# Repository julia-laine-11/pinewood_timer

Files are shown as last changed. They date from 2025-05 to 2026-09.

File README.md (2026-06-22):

# pinewood_timer
Timer system for a pinewood derby track. My grandma asked me to help her make one since her boy scout troop's track does not have one. I hope that I can make these more affordable so that her troop and other troops can get accurate timers that dont cost an arm and a leg.

*so whats in here?*
### [Hardware:](https://github.com/julia-laine-11/pinewood_timer/tree/main/Hardware)
* display_15_in
    - schematic
    - pcb
    - holds all the 7-segment displays and sensor receivers at the end of the track

* mainboard
    - schematic
    - pcb
    - holds the brains for the system
    - also where the power cable goes

### [Software:](https://github.com/julia-laine-11/pinewood_timer/blob/main/Software/code.md)
  - readme
* [Program](https://github.com/julia-laine-11/pinewood_timer/tree/main/Software/code/pinewood_program)
  - platformio project

### Overview
#### Overall Requirements
- easy operation -> plug and play
- 4 lanes
- time to the thousandths
- displays time in each lane
- displays placement in each lane
- cost less than $100-$120
    - 

##### Requirements per each lane
- start sensor - same trigger for all lanes
- stop sensor - seperate per each lane
- time display - 4 seven seg displays
- placement display - 1 larger seven seg display

##### Sensors
- Start sensor triggered by lever release
  - Microswitch is easy to install and get output from
  - I have to wait and see what my grandfather builds as the start mechanism
- Stop sensor - IR LED and IR Receiver
  - Sits in the middle of the groove the cars ride on underneath the finish line
  - Since it will likely be in a gym, the IR receiver should point down for less interference from the large lamps
  - A comparator or the STM ADC can be used if the voltage doesnt drop to an amount the STM recognizes as 0

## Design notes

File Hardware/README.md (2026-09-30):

## Contents:

so i am editing this board right now. i took the senior design pcb and made it into a zombie version that might connect to this.

some fixes that will be made:

- d+ - flip
- connector footprint
- stm connection

- [display_15_in](https://github.com/julia-laine-11/pinewood_timer/tree/main/Hardware/display_15_in)
*will be printed
   - whats inside:
    - kicad project
      - schematic
      - pcb
  - about:
    - combines placement_disp and timer_display_pcb since it is cheaper to put both on the same pcb - even though its so much larger
    - also includes the sensors for the end of track

- [mainboard](https://github.com/julia-laine-11/pinewood_timer/tree/main/Hardware/mainboard)
*will be printed
  - whats inside:
    - kicad project
      - schematic
      - pcb
  - about:
    - main board where the stm32f091rct6 lives
    - jst connectors to each board/input/output around the system

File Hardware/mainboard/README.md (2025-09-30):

## mainboard

This board will be placed in a central location on the track. It connects to the power, reset button, start sensors, display at the end, and end sensors. A usb-c power supply will power it.

#### Current Board

9/30/25 - today i soldered the LED on. i got scared it wasnt working, but it turns out it was just a blue LED and therefore needed a smaller resistor. Then i plugged it in and i thought hte JTAG was backwards, but it turns out the decoup capacitors I placed are not in face decoupling and just capacitors. so i removed them and added a wire around them. im having issues connecting to the board. 

i got access to the board files from ece362, so i plan on comparing my layout to theirs to see what i did wrong. im disappointed but i think i can fix it (hopefully)



#### Current schematic
8/7/25 - fixed little silkscreen words. fixed DRC violations



### Old:

8/5/25 - i actually routed stuff today wohoo. i also added the design rules because i forgot to do that












not too much changed about the schematic:

i just added this for the start switch because i forgot about it


8/3/25 - added connectors and sheets









7/27/25 - organized and fixed power



7/26/25 - changed stm. added jtag. added usb for power. edited 3v3 supply. current schematic messy but its still in the works



Unfinished schematic

missing:
- connectors
- power in
- jtag
- usb - ttl



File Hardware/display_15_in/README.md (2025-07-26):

## display_15_in
This was originally going to be a few seperate boards. I thought it would be easier and cheaper to make. 

It turns out to be cheaper to do it this way since the price of printing 3-4 boards per track and the price of 1 big one is the same. Also, with multiple boards you have to buy connectors and this 1 large board needs way less than 4 small ones.

This board connects to the main board with 1 8x2 connector and 1 12x2 connector.

### Parts
- LTS-3401LG - single 7-seg displays
- 4x TDCR1050M - quad 7-seg displays
- 20x PN2907A - cathode select bjt
- 20x 150 Ohm - mux to bjt
- 16x 47 Ohm - driver to display
- 2x 74HC138 - mux
- 2x TLC59211 - driver

#### pictures



>size comparison of digits 

#### schematics








#### PCB

Updated:

- still needs
  - power and ground traces
  - drill holes for mounting
  - test points

All traces routed (for now)











#### Log

7/12/25 - moved all of the components needed over to one project

7/13/25 - worked out connections between sheets and found connectors for mainboard. began layout (no traces)

7/19/25 - laying more traces and revising old ones. i am starting to hate the connector but i must use it



7/20/25 - sorted out the connector from hell. well, i at least made it better. i also discovered the "distribute evenly" and "align" functions



7/25/25 - finished traces, added test points



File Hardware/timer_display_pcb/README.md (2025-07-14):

## timer_display_pcb
This PCB will not be used. the [display_15_in](https://github.com/julia-laine-11/pinewood_timer/tree/main/Hardware/display_15_in) will be used instead

### Parts
4x TDCR1050M - 7-seg displays
16x PN2907A - cathode select bjt
16x 150 Ohm - mux to bjt
16x 47 Ohm - driver to display
2x 74HC138 - mux
2x TLC59211 - driver

### Pictures

Circuit:





Timer display vs placement display sizing



[comment]: <>
[comment]: <>
[comment]: <>
[comment]: <>

#### PCB V1
I am writing this as V1 since I am coming to the realization that it is the same price to order three seperate boards and connecting them together as it is to just buy one 3"x15" PCB. I will probably still order one of these since 5x is $2.00, but for the actual track it will be easier to install just one board.

- Schematic



[comment]: <>

- Front




[comment]: <>
[comment]: <>
- Back




[comment]: <>
[comment]: <>

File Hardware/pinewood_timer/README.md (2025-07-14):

## pinewood_timer

This is just a schematic of the overall system. it has gotten messy as I have gutted it to use its pieces in other parts of the project.

This will not be printed or used but I plan to clean it up when I am done

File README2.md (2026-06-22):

# Pinewood Derby Timer — Software & Operations Guide

A four-lane pinewood derby finish-line timer built around the **STM32F091RCT6**.  
This document describes the firmware, pin map, serial interface, and day-of-race behavior.

> The original project readme is unchanged at [README.md](README.md).  
> Firmware file index: [Software/code/pinewood_program/INDEX.md](Software/code/pinewood_program/INDEX.md)

---

## What it does

- **Four independent lane timers** start together when the release lever triggers **PC11**.
- Each timer **stops** when its car breaks the IR beam at the finish (**PB11–PB14**).
- **Quad 7-segment displays** above each lane show elapsed time to **0.001 s** (e.g. `1.234`).
- **Large placement digits** show finish order (1st, 2nd, …) as each car crosses; other lanes keep counting until they finish.
- **Reset** clears times and placements (GPIO button on **PA15**, or serial `R`).
- **Status LEDs** on the mainboard: READY / RUNNING / FINISHED.
- **Serial output** over **USART5** (**PC12** TX, **PD2** RX) at 115200 baud via an **FT232RL** USB-TTL adapter.

---

## Hardware context

| Board | Role |
|---|---|
| **mainboard** | STM32, power, JTAG, connectors, status LEDs, start/reset |
| **display_15_in** | All 7-segment displays, IR receivers, TLC59211 drivers, 74HC138 mux |

Display driving: **TLC59211** LED drivers (parallel D1–D8 + CLK) and **74HC138** decoders for digit/lane multiplexing. See KiCad schematics under `Hardware/`.

---

## Toolchain

- **MCU:** STM32F091RCT6 @ 48 MHz
- **IDE:** VS Code + PlatformIO
- **Upload:** JTAG / SWD via OpenOCD (`Software/code/pinewood_program/openocd.cfg`)
- **Serial:** FT232RL on USART5 — **PC12** (MCU TX) and **PD2** (MCU RX)

### Build

```bash
cd Software/code/pinewood_program
pio run
pio run -t upload
pio device monitor -b 115200
```

Wire FT232RL: **MCU PC12 → adapter RX**, **MCU PD2 ← adapter TX**, common GND.

---

## Pin map (MCU)

Every mask is the bit index in the GPIO port (bit *N* = pin **PN**).

### Timer displays

| Pins | Port | Lanes |
|---|---|---|
| PB0–PB7 | GPIOB | Segment data (TLC59211 D1–D8), lanes 1–2 |
| PB8–PB10 | GPIOB | Mux A0–A2 (74HC138) |
| PC0–PC7 | GPIOC | Segment data, lanes 3–4 |
| PC8–PC10 | GPIOC | Mux A0–A2 |

### Placement displays

| Pins | Port | Role |
|---|---|---|
| PA0–PA7 | GPIOA | Segment data |
| PA8–PA10 | GPIOA | Mux A0–A2 |

### Sensors & buttons

| Pin | Hex mask | Input |
|-----|---|---|
| **PC11** | `0x0800` | Start — shared by all lanes |
| **PA15** | `0x8000` | Reset button *(placeholder; change in `pins.h` if routed elsewhere)* |
| **PB11** | `0x0800` | Lane 1 finish IR |
| **PB12** | `0x1000` | Lane 2 finish IR |
| **PB13** | `0x2000` | Lane 3 finish IR |
| **PB14** | `0x4000` | Lane 4 finish IR |

**Note:** **PC12** is **not** the reset button — it is **USART5_TX**.

### Serial (USART5 / “UART5”)

| Pin | Hex mask | Direction |
|-----|---|---|
| **PC12** | `0x1000` | TX → FT232RL RX |
| **PD2** | `0x0004` | RX ← FT232RL TX |

### Status LEDs (active high)

| Pin | Hex mask | Meaning |
|-----|---|---|
| **PC13** | `0x2000` | READY (idle) |
| **PC14** | `0x4000` | RUNNING |
| **PC15** | `0x8000` | FINISHED |

Full definitions with comments: [`Software/code/pinewood_program/src/pins.h`](Software/code/pinewood_program/src/pins.h).

---

## Operation

1. Power on — **READY** LED on, serial prints `PINEWOOD READY`.
2. Press reset (or send `R`) if needed to clear a previous race.
3. Release the start lever — all four timers begin; **RUNNING** LED on; serial prints `START`.
4. As each car crosses the finish IR, that lane’s time **freezes**, placement digit appears, serial prints e.g. `FIN 1 2847 1` (lane 1, 2.847 s, 1st place).
5. When all four have finished, **FINISHED** LED on.
6. Reset for the next heat.

Lanes that have not finished continue to increment on the display; finished lanes show their frozen time and placement.

---

## Serial protocol

Baud: **115200**, 8 data bits, no parity, 1 stop bit.

### Automatic messages (MCU → PC)

```
PINEWOOD READY
START
FIN <lane> <time_ms> <place>
RESET
```

- `<lane>` — 1 to 4  
- `<time_ms>` — integer milliseconds (display as `<time_ms>/1000` seconds)  
- `<place>` — 1 to 4  

Example: `FIN 2 3102 2` → lane 2 finished second with time 3.102 s.

### Commands (PC → MCU)

| Character | Action |
|---|---|
| `R` or `r` | Reset race |
| `?` | Reply with state and all lane times |

Example query response: `STATE 1 T1 1200 T2 980 T3 0 T4 0`  
(`STATE` 0=idle, 1=running, 2=finished; `T1`…`T4` in ms)

---

## Firmware architecture

```
main.c          Boot, GPIO, timers, ISRs
clock.c         48 MHz clock
pins.h          Pin map and mux constants
race.c          State machine, 1 kHz time base, placement queue
display.c       2 kHz display multiplexing
uart.c          USART5 logging and commands
font.h          7-segment patterns
```

### Timing (matches [Software/code.md](Software/code.md))

| Rate | Source | Task |
|---|---|---|
| 1 kHz | TIM14 | Increment each running lane timer |
| 2 kHz | TIM6 | Debounce inputs; refresh timer L1–2, L3–4, placement displays |

### Time format

Internal value is an integer counting **milliseconds** at 1 kHz.  
The display always shows a decimal point after the first digit: value `1234` → **1.234**.

### Placement algorithm

Queue starts at **1234** (meaning places 1, 2, 3, 4 are still to assign):

1. Next place = `queue / 1000`
2. Update queue = `(queue % 1000) * 10`

First finisher gets **1**, second **2**, and so on.

---

## Configuration

Edit [`Software/code/pinewood_program/src/pins.h`](Software/code/pinewood_program/src/pins.h):

| Macro | Purpose |
|---|---|
| `RESET_PORT` / `RESET_PIN_MASK` | Reset button location (default **PA15**) |
| `BUTTON_ACTIVE_HIGH` | Set to 0 if switches pull low when pressed |
| `FINISH_SENSOR_ACTIVE_HIGH` | Set to 0 if IR pulls low when beam breaks |
| `lane*_mux_addr` presets | Tune if wrong digit or lane lights up |

---

## Troubleshooting

| Symptom | Check |
|---|---|
| No upload | JTAG wiring, `openocd.cfg`, power to board |
| Garbled serial | 115200 baud, TX/RX not swapped, common GND |
| Timer never starts | **PC11** start wiring and `BUTTON_ACTIVE_HIGH` |
| Lane never stops | Finish pin **PB11–PB14** and `FINISH_SENSOR_ACTIVE_HIGH` |
| Wrong display digit | Mux constants in `pins.h` (380/580/680/700 presets) |
| Reset does nothing | **PA15** routing, or use serial `R` |

---

## Repository layout

```
pinewood_timer/
├── README.md              ← original readme (do not replace)
├── README2.md             ← this file
├── Hardware/              ← KiCad PCBs and schematics
└── Software/
    ├── code.md            ← original firmware design notes
    └── code/pinewood_program/
        ├── INDEX.md       ← source file index
        ├── platformio.ini
        ├── openocd.cfg
        └── src/           ← firmware
```

---

Built for scout troops who need an accurate, affordable track timer. Good luck at the derby.

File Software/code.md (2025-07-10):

I am using an stm32f091rct6 for this project
- vscode with platformio extension
- jtag and usb to ttl

vars

- 1x placement -> int 1234
  
    when ir sensor crossed 
    1234 / 1000 (as an int) gives 1st number
    to update: (1234 % 1000) * 10 brings it to 2340 and its ready for the next one

- 4x times -> int xxxx
  
    dp is always on so i dont have to deal with decimals :)
    counts up to 1 with each 1khz tick
        starts -> interrupt enabled by lever
        stops  -> interrupt disabled by lever

- 4x running -> 1 or 0
      0 at reset
      1 when lever
      0 when ir crossed

control 

faster than 1khz (probs 2k is ok)
- check lever
- check ir lane 1 
- check ir lane 2
- check ir lane 3
- check ir lane 4

faster than updates (1k < refresh rate < 2k)
- run lanes 1 & 2 disp
- run lanes 2 & 3 disp
- run score disp

exactly 1khz
- update time for each lane

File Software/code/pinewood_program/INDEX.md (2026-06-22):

# Pinewood Timer — Software Index

Documentation map for the PlatformIO firmware in this folder.  
For project background and hardware overview, see [README2.md](../../README2.md) at the repo root.

---

## Quick links

| Document | Purpose |
|---|---|
| [README2.md](../../README2.md) | Full project readme (software + operation) |
| [../code.md](../code.md) | Original design notes (variables, timing plan) |
| [../../README.md](../../README.md) | Original repo readme (unchanged) |
| [platformio.ini](platformio.ini) | Build, upload, and monitor settings |
| [openocd.cfg](openocd.cfg) | JTAG / SWD upload via OpenOCD |
| [src/pins.h](src/pins.h) | **Authoritative GPIO pin map** |

---

## Source files

| File | Role |
|---|---|
| [src/main.c](src/main.c) | Entry point, GPIO setup, timer init, ISR wiring |
| [src/clock.c](src/clock.c) | 48 MHz PLL from internal HSI |
| [src/pins.h](src/pins.h) | Pin names, masks, mux presets, polarity flags |
| [src/race.c](src/race.c) | Race state machine, timers, placement queue, sensor debounce |
| [src/race.h](src/race.h) | Public race API and `race_state_t` enum |
| [src/display.c](src/display.c) | 7-segment multiplexing (TLC59211 + 74HC138) |
| [src/display.h](src/display.h) | Display driver API |
| [src/font.h](src/font.h) | Segment patterns for digits 0–9 |
| [src/uart.c](src/uart.c) | USART5 serial (PC12 TX, PD2 RX), `printf` retarget |
| [src/uart.h](src/uart.h) | UART init and race log helpers |

---

## Interrupts and timing

| IRQ handler | Timer | Rate | Work |
|---|---|---|---|
| `TIM14_IRQHandler` | TIM14 | **1 kHz** | Increment running lane times |
| `TIM6_DAC_IRQHandler` | TIM6 | **2 kHz** | Poll start/reset/finish inputs; mux displays; update status LEDs |
| `USART3_4_5_6_IRQHandler` | USART5 | async | Handle serial commands (`R`, `?`) |

System clock: **48 MHz** (`board_build.f_cpu` in `platformio.ini`).

---

## GPIO summary

### Displays (output)

| Bank | MCU pins | Function |
|---|---|---|
| Placement | **PA0–PA10** | 4 large placement digits |
| Timer L1–L2 | **PB0–PB10** | Quad 7-seg timers, lanes 1 & 2 |
| Timer L3–L4 | **PC0–PC10** | Quad 7-seg timers, lanes 3 & 4 |

Each bank: **PA/PB/PC 0–7** = segment data, **8–10** = 74HC138 mux A0–A2.

### Inputs

| Pin | Mask | Function |
|-----|---|---|
| **PC11** | `0x0800` | Start lever (all lanes) |
| **PA15** | `0x8000` | Reset button (placeholder pin) |
| **PB11** | `0x0800` | Lane 1 finish IR |
| **PB12** | `0x1000` | Lane 2 finish IR |
| **PB13** | `0x2000` | Lane 3 finish IR |
| **PB14** | `0x4000` | Lane 4 finish IR |

### UART5 (FT232RL)

| Pin | Mask | Function |
|-----|---|---|
| **PC12** | `0x1000` | USART5_TX → adapter RX |
| **PD2** | `0x0004` | USART5_RX ← adapter TX |

### Status LEDs (output, active high)

| Pin | Mask | LED |
|-----|---|-----|
| **PC13** | `0x2000` | READY |
| **PC14** | `0x4000` | RUNNING |
| **PC15** | `0x8000` | FINISHED |

---

## Serial protocol (115200 8N1)

**MCU → PC (automatic on events)**

| Line | Meaning |
|---|---|
| `PINEWOOD READY` | Boot complete |
| `START` | Race started |
| `FIN <lane> <time> <place>` | Lane finished (lane 1–4, time in ms, place 1–4) |
| `RESET` | Race cleared |

**PC → MCU (send single character)**

| Key | Action |
|-----|---|
| `R` or `r` | Reset race |
| `?` | Print state and four lane times |

---

## Race logic (from `code.md`)

- **Time** — 16-bit counter per lane; +1 every 1 ms while running. Display as **d.ddd** (e.g. `1234` → **1.234** s).
- **Placement queue** — starts at `1234`; each finish takes `queue/1000` as place, then `queue = (queue % 1000) * 10`.
- **Running flag** — per lane; cleared when that lane’s IR triggers.
- **States** — `IDLE` → `RUNNING` → `FINISHED` (or back to `IDLE` on reset).

---

## Build and upload

```bash
cd Software/code/pinewood_program
pio run
pio run -t upload
pio device monitor
```

Upload uses OpenOCD + JTAG (`openocd.cfg`). Serial monitor: **115200** baud.

---

## Tuning checklist

1. **Wrong digit / lane on display** — edit mux presets in [src/pins.h](src/pins.h) (`0x017C`, `0x0244`, `0x02A8`, `0x02BC`).
2. **Sensor polarity wrong** — set `BUTTON_ACTIVE_HIGH` / `FINISH_SENSOR_ACTIVE_HIGH` in [src/pins.h](src/pins.h).
3. **Reset pin moved** — update `RESET_PORT` / `RESET_PIN_MASK` in [src/pins.h](src/pins.h) (PC12 is UART TX).
4. **No serial** — check FT232 wiring to PC12/PD2 and COM port in PlatformIO monitor.

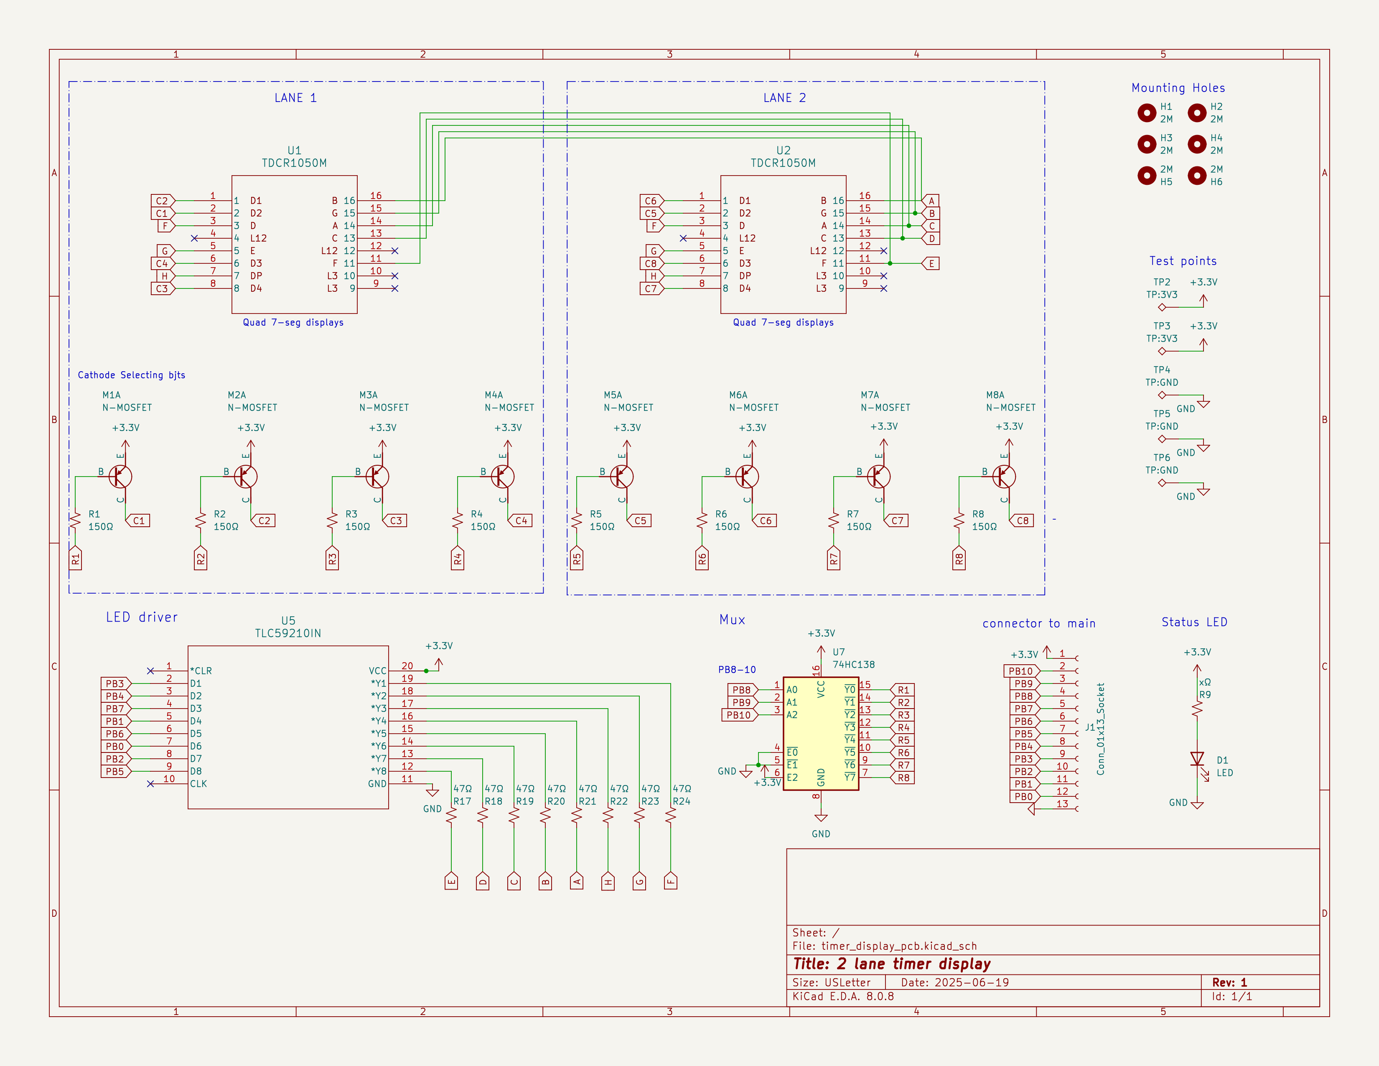
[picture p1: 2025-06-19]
Hardware/timer_display_pcb/schematic.png

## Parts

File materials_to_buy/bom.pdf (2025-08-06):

part # | Description | # | $ single $ all
1 | PT204-6B | IR SENSOR | 25 0.23600 | $5.90
2 | MMBT4403 | TRANSISTOR - DISPLAY SELECT | 125 0.04420 | $5.53
3 | SN74HC138DR | MUX | 25 0.16200 | $4.05
4 | RK73B2ATTD151J | 150 OHM | 125 0.01390 | $1.74
5 | TLC59211IPWR | LED DRIVER | 12 1.09600 | $13.15
6 | RK73B2ATTD510J | 51 OHM | 140 0.01390 | $1.95
7 | IR333-A | IR LED | 25 0.29600 | $7.40
8 | 302-S101 | JTAG CONNECTOR | 10 0.22400 | $2.24
9 | KUSBX-SMT-CS-6-BTR | USB-C PORT | 10 0.61900 | $6.19
10 | SMAZ5V1-13-F | DIODE | 15 0.16600 | $2.49
11 | CL21A226KQQNNNE | 22UF CAPACITOR | 20 0.11500 | $2.30
12 | C0805C103K5RACTU | 10,000PF CAPACITOR | 10 0.02000 | $0.20
13 | CL21B105KBFNNNE | 1UF CAPACITOR | 20 0.01900 | $0.38
14 | CC0805KRX7R9BB104 | .1UF CAPACITOR | 50 0.01600 | $0.80
15 | CC0805JRNPO9BN100 | 10PF CAPACITOR | 20 0.04800 | $0.96
16 | ECS-2520MV-160-CN-TR | 16MHZ CAP | 10 0.96600 | $9.66
17 | 60900213421 | BOOT JUMPER | 10 0.27900 | $2.79
18 | CRGCQ0805F220R | 220 OHM | 30 0.02720 | $0.82
19 | RR1220P-103-D | 10K OHM | 10 0.03100 | $0.31
20 | RC0805FR-071K5L | 1K5 OHM | 10 0.01600 | $0.16
21 | CL21A106KOQNNNE | 10UF | 10 0.05100 | $0.51
22 | LTL-4234 | GREEN LED | 35 0.10200 | $3.57
23 | AMS1117-3.3 | LINEAR REG | 10 0.18200 | $1.82
24 | STM32F091RCT6 | MICROCONTROLLER | 6 6.08000 | $36.48
25 | ILHB0805ER121V | FERRITE BEAD | 10 0.07400 | $0.74
26 | S16B-PHDSS | 16 PIN HEADER | 10 0.43400 | $4.34
27 | PTS636SK25FSMTR LFS | RESET BUTTON | 10 0.21100 | $2.11
28 | PHDR-16VS | 16 PIN HEADER - CONNECTOR | 10 0.23300 | $2.33
29 | 0513532400 | 24 PIN HEADER | 10 0.66800 | $6.68
30 | 0559592430 | 24 PIN HEADER - CONNECTOR | 10 0.92600 | $9.26

total: $136.86
5x: | $27.37
3x: | $45.62

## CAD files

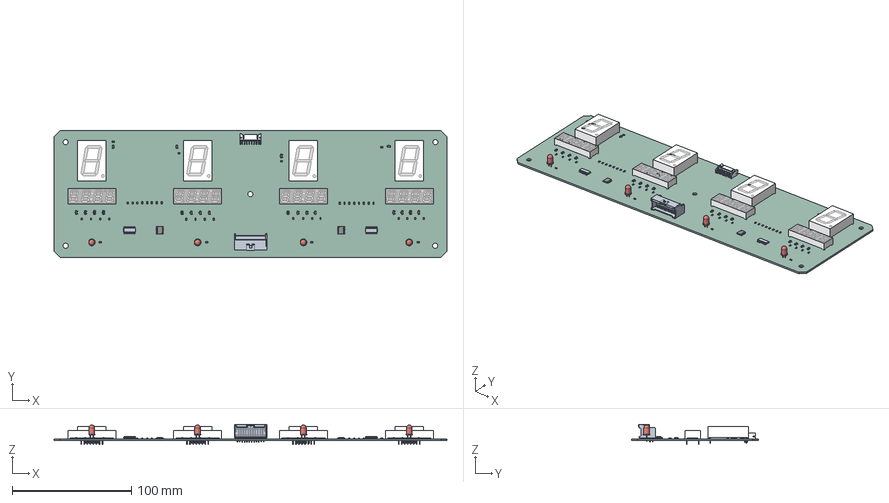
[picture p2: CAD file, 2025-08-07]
Hardware/display_15_in/display_15_in.step
330.2 x 106.7 x 17.1 mm
R_0805_2012Metric x 40
F415-6 x 4
LED_D5.0mm x 4
XDxx25x x 4
D16 x 2
S16B-PHDSS
PW20 x 2
display_15_in_PCB

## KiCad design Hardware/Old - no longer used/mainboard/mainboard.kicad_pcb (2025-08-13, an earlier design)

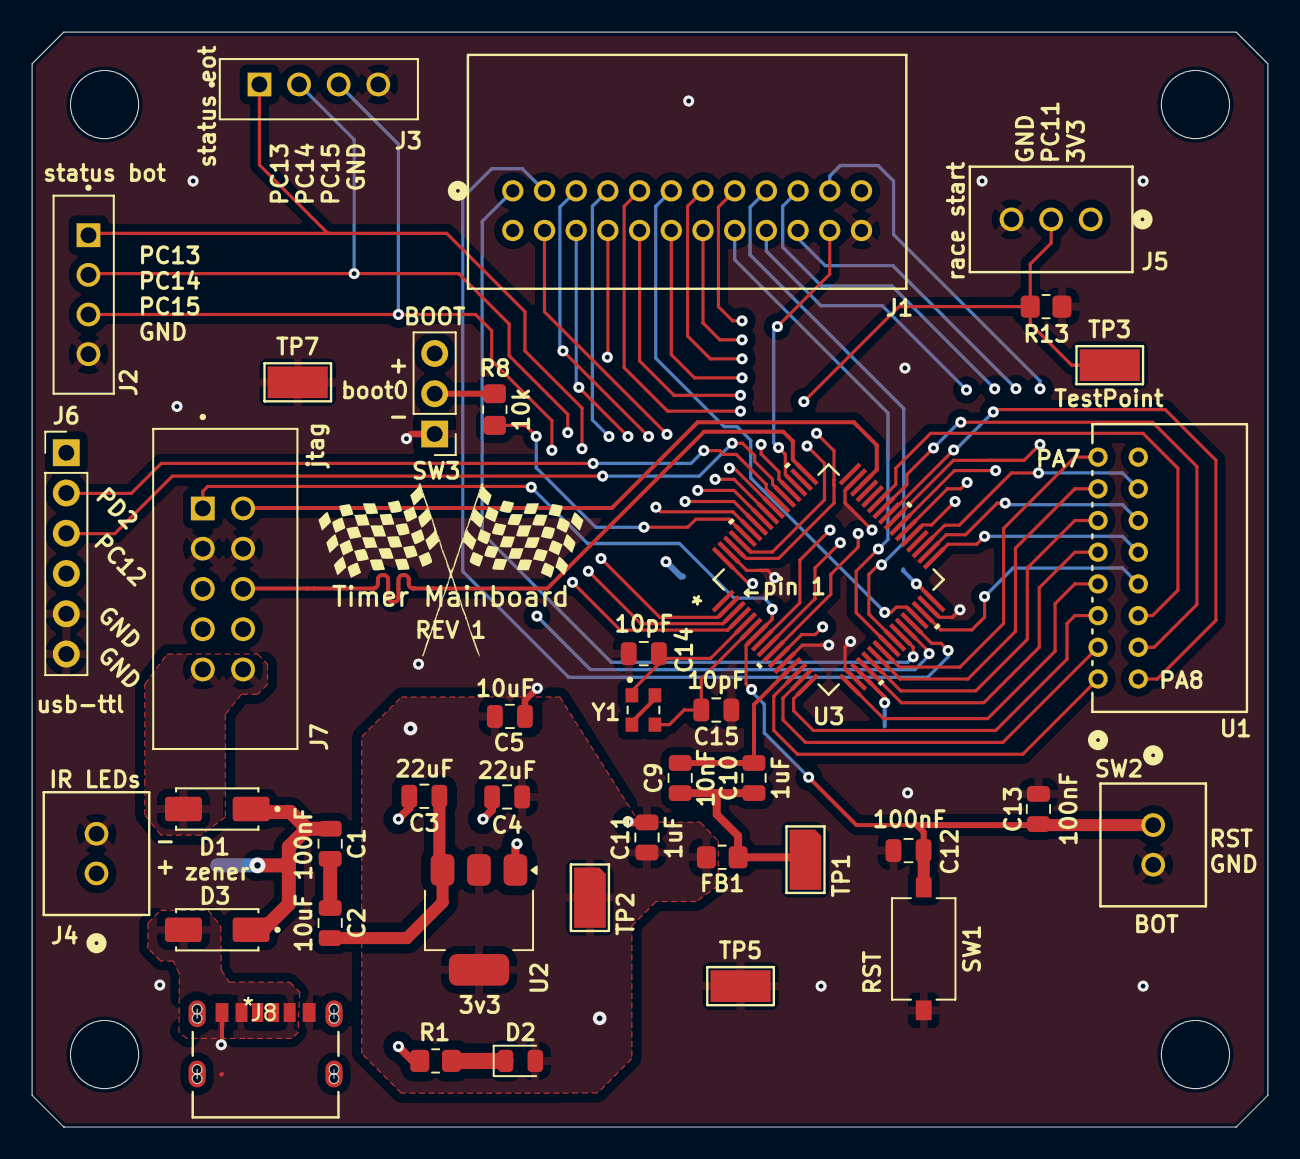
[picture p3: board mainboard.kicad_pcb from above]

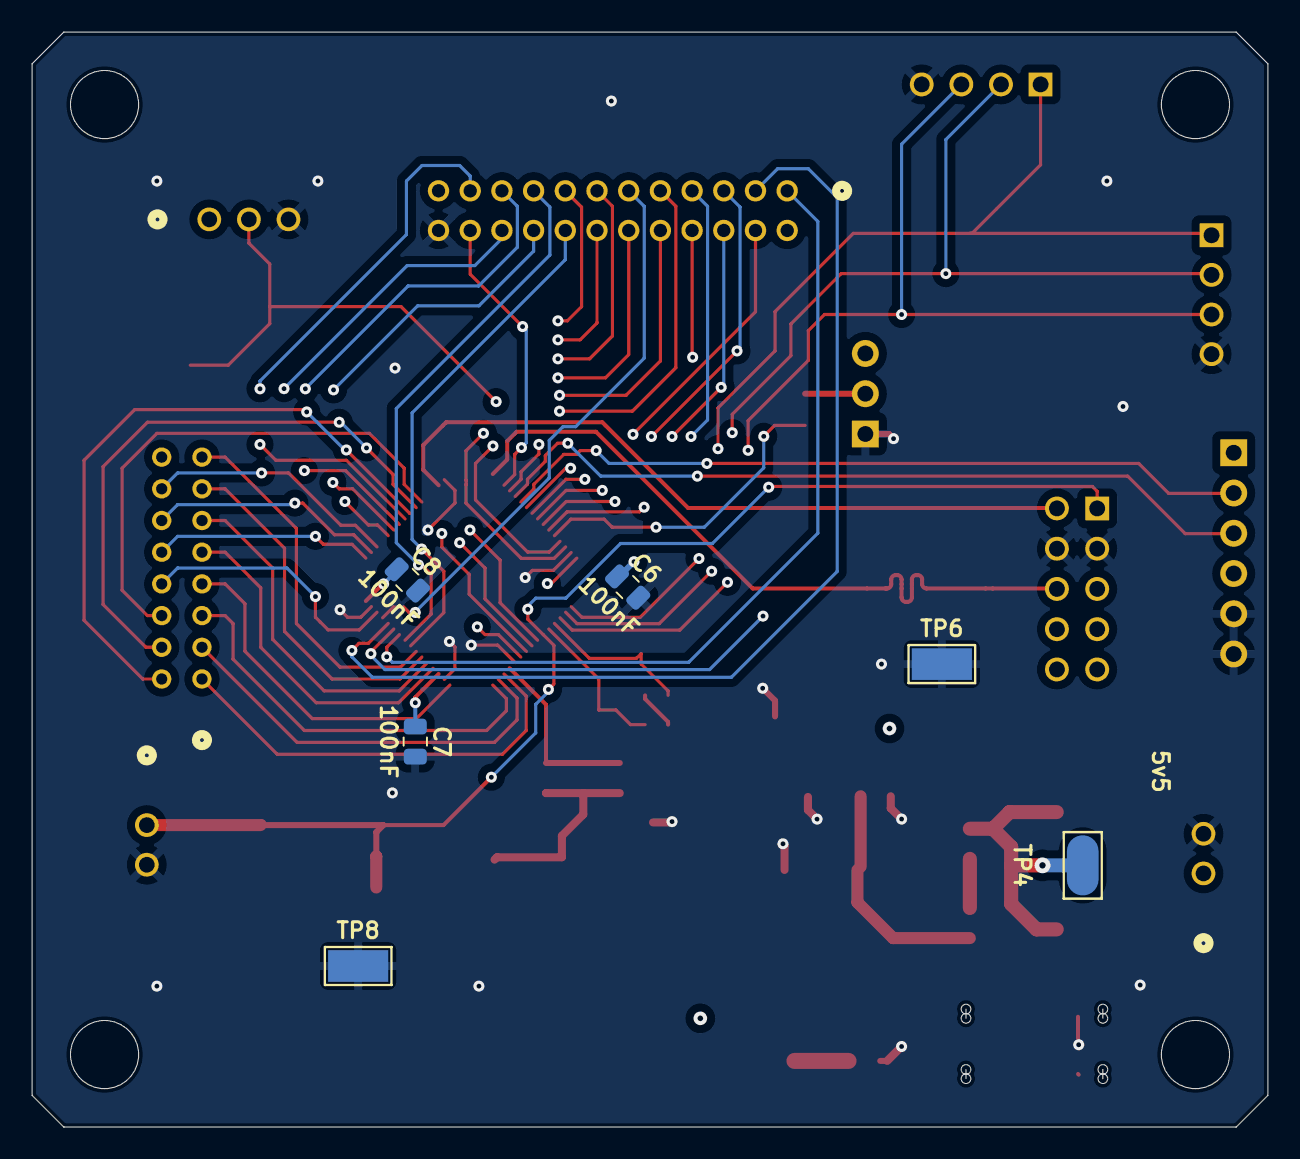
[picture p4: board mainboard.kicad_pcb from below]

Board: 4 copper layers, 78.0 x 69.1 mm, 49 parts (6 on the bottom side), 61 nets.

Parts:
C1, C6, C7, C8, C12, C13: 100nF; C_0805_2012Metric
C2, C5: 10uF; C_0805_2012Metric
C3, C4: 22uF; C_0805_2012Metric
C9: 10nF; C_0805_2012Metric
C10, C11: 1uF; C_0805_2012Metric
C14, C15: 10pF; C_0805_2012Metric
D1, D3: zener; DIOM5226X240N
D2: LED; D_0805_2012Metric
FB1: FerriteBead; R_0805_2012Metric_Pad1.20x1.40mm_HandSolder
H1, H2, H3, H4: MountingHole; MountingHole_4.3mm_M4_DIN965
J1: 559592430; CONN24_559592430_MOL
J2: status bot; 1x04_jst
J3: status eot; 1x04_jst
J4: B02B-XASK-1LFSN; 1X02_JST
J5: race start; 1X03_JST
J6: usb-ttl; PinHeader_1x06_P2.54mm_Vertical
J7: jtag; SULLINS_SBH11-PBPC-D05-ST-BK
J8: KUSBX-SMT-CS-6-BTR; 2171750001_MOL
R1: 1k5; R_0805_2012Metric_Pad1.20x1.40mm_HandSolder
R8: 10k; R_0805_2012Metric_Pad1.20x1.40mm_HandSolder
R13: R_US; R_0805_2012Metric_Pad1.20x1.40mm_HandSolder
SW1: ON-BOARD; SW_Tactile_SPST_NO_Straight_CK_PTS636Sx25SMTRLFS
SW2: BOT; CONN_B02B-XASK-1LFSN_JST
SW3: BOOT; PinHeader_1x03_P2.54mm_Vertical
TP1, TP2, TP3, TP4, TP5, TP6, TP7, TP8: TestPoint; TestPoint_Keystone_5019_Minature
U1: S16B-PHDSSLFSN; S16B-PHDSSLFSN_JST
U2: AMS1117-3.3; SOT-223-3_TabPin2
U3: STM32F091RCTx; STM32F091RCT6-M
Y1: Crystal_GND24; OSC_ECS-2520S25-250-FN-TR

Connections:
+3.3V: C4.1, C5.1, C6.1, C7.1, C8.1, C11.1, D2.2 (A), FB1.2, J1.23, J4.1, J5.1, SW3.3 (C), TP2.1, U2.2 (VO), U3.19 (VDD), U3.32 (VDD), U3.64 (VDD)
+3.3VA: C9.1, C10.1, FB1.1, TP1.1
/programming/3V3 REG DECOUP: C1.2, C2.1
/programming/3v3_reg_in: C2.2, C3.1, U2.3 (VI)
/programming/5v5_in_jtag: D1.2, J7.9, J7.10
/programming/5v5_post_diode: C1.1, D1.1, D3.1, TP4.1
/programming/5v5_usb: D3.2, J8.A9 (VBUS), J8.B9 (VBUS)
/programming/PWR_LED_CATHODE: D2.1 (K), R1.2
/stm/BOOT0: R8.2, U3.60 (PF11)
/stm/HSE_IN: C14.1, U3.5 (PF0), Y1.1
/stm/HSE_OUT: C15.1, U3.6 (PF1), Y1.3
/stm/SW_BOOT0: R8.1, SW3.2 (B)
GND: C3.2, C4.2, C5.2, C6.2, C7.2, C8.2, C11.2, C12.2, C13.2, C14.2, C15.2, J1.24, J2.4, J3.4, J4.2, J5.3, J6.5, J6.6, J7.3, J7.4, J8.A12 (GND), J8.B12 (GND), R1.1, R13.2, SW1.2 (B), SW2.2 (B), SW3.1 (A), TP5.1, TP6.1, TP7.1, TP8.1, U2.1 (GND), U3.12 (VSSA), U3.18 (VSS), U3.31 (VSS), U3.47 (VSS), U3.63 (VSS)
unnamed: C9.2, C10.2, U3.13 (VDDA)
unnamed: Y1.2, Y1.4
PA0: U1.1, U3.14 (PA0)
PA1: U1.2, U3.15 (PA1)
PA2: U1.3, U3.16 (PA2)
PA3: U1.4, U3.17 (PA3)
PA4: U1.5, U3.20 (PA4)
PA5: U1.6, U3.21 (PA5)
PA6: U1.7, U3.22 (PA6)
PA7: U1.8, U3.23 (PA7)
PA8: U1.9, U3.41 (PA8)
PA9: U1.10, U3.42 (PA9)
PA10: U1.11, U3.43 (PA10)
PB0: J1.1, U3.26 (PB0)
PB1: J1.2, U3.27 (PB1)
PB2: J1.3, U3.28 (PB2)
PB3: J1.4, U3.55 (PB3)
PB4: J1.5, U3.56 (PB4)
PB5: J1.6, U3.57 (PB5)
PB6: J1.7, U3.58 (PB6)
PB7: J1.8, U3.59 (PB7)
PB8: J1.9, U3.61 (PB8)
PB9: J1.10, U3.62 (PB9)
PB10: J1.11, U3.29 (PB10)
PB11: U1.12, U3.30 (PB11)
PB12: U1.13, U3.33 (PB12)
PB13: U1.14, U3.34 (PB13)
PB14: U1.15, U3.35 (PB14)
PC0: J1.12, U3.8 (PC0)
PC1: J1.13, U3.9 (PC1)
PC2: J1.14, U3.10 (PC2)
PC3: J1.15, U3.11 (PC3)
PC4: J1.16, U3.24 (PC4)
PC5: J1.17, U3.25 (PC5)
PC6: J1.18, U3.37 (PC6)
PC7: J1.19, U3.38 (PC7)
PC8: J1.20, U3.39 (PC8)
PC9: J1.21, U3.40 (PC9)
PC10: J1.22, U3.51 (PC10)
PC11: J5.2, R13.1, TP3.1, U3.52 (PC11)
PC12: J6.3, U3.53 (PC12)
PC13: J2.1, J3.1, U3.2 (PC13)
PC14: J2.2, J3.2, U3.3 (PC14)
PC15: J2.3, J3.3, U3.4 (PC15)
PD2: J6.2, U3.54 (PD2)
RST: C12.1, C13.1, J7.1, SW1.1 (A), SW2.1 (A), U3.7 (NRST)
SWCLK: J7.6, U3.49 (PA14)
SWDIO: J7.2, U3.46 (PA13)

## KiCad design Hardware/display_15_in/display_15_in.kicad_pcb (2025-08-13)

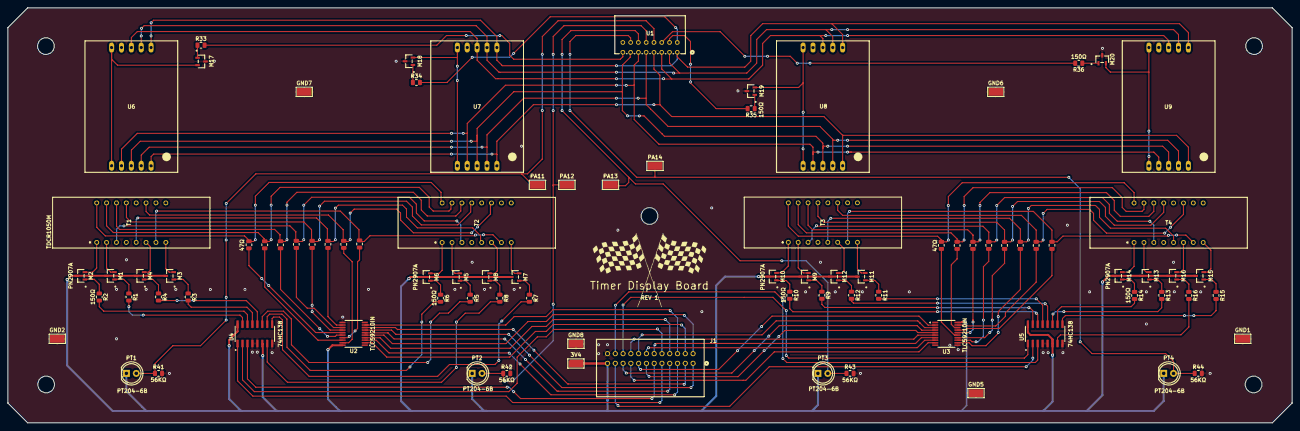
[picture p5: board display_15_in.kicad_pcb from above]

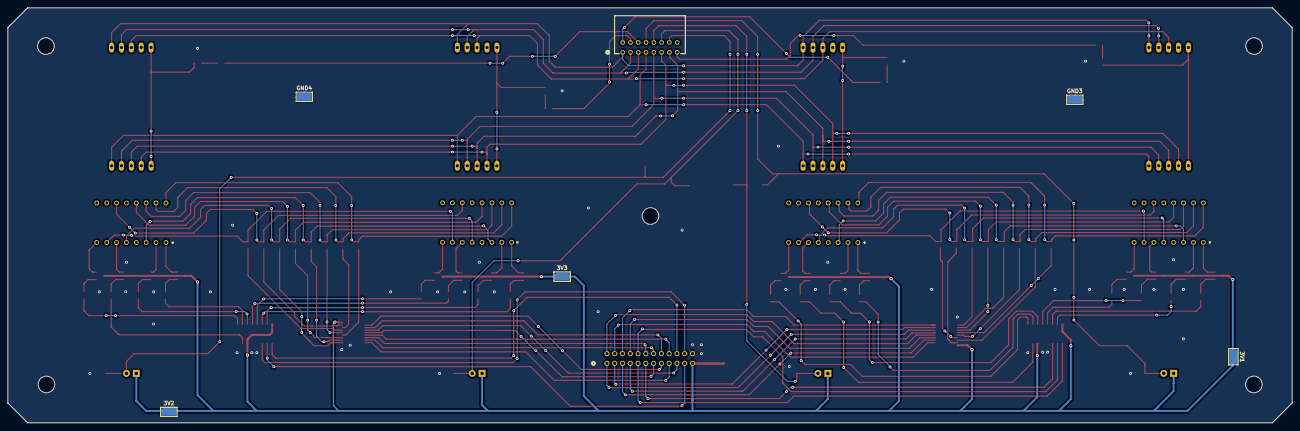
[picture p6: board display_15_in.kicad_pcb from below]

Board: 2 copper layers, 330.2 x 106.7 mm, 94 parts (5 on the bottom side), 127 nets.

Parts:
3V1, 3V2, 3V3, 3V4: TestPoint; TestPoint_Keystone_5019_Minature
GND1, GND2, GND3, GND4, GND5, GND6, GND7, GND8: TestPoint; TestPoint_Keystone_5019_Minature
J1: 559592430; CONN24_559592430_MOL
M1, M3, M4, M5, M6, M7, M8, M9, M10, M11, M12, M13, M14, M15, M16, M17, M18, M19, M20: N-MOSFET; TO-236AB_SOT23_NEX
M2: PN2907A; TO-236AB_SOT23_NEX
PA11, PA12, PA13, PA14: TP; TestPoint_Keystone_5019_Minature
PT1, PT2, PT3, PT4: LED_D5.0mm
R1, R2, R3, R4, R5, R6, R7, R8, R9, R10, R11, R12, R13, R14, R15, R16, R33, R34, R35, R36: 150Ω; R_0805_2012Metric
R17, R18, R19, R20, R21, R22, R23, R24, R25, R26, R27, R28, R29, R30, R31, R32: 47Ω; R_0805_2012Metric
R41, R42, R43, R44: 56KΩ; R_0805_2012Metric
T1, T2, T3, T4: TDCR1050M; TDCG1060M_VIS
U1: S16B-PHDSSLFSN; S16B-PHDSSLFSN_JST
U2, U3: TLC59210IN; SOP65P640X120-20N
U4, U5: 74HC138; SOIC127P600X175-16N
U6, U7, U8, U9: SA39-12YWA; LDS-AA14RI

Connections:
+3.3V: 3V1.1, 3V2.1, 3V3.1, 3V4.1, J1.23, M1.3, M2.3, M3.3, M4.3, M5.3, M6.3, M7.3, M8.3, M9.3, M10.3, M11.3, M12.3, M13.3, M14.3, M15.3, M16.3, PT1.1 (+), PT2.1 (+), PT3.1 (+), PT4.1 (+), U2.20 (VCC), U3.20 (VCC), U4.6 (E2), U4.16 (VCC), U5.6 (E2), U5.16 (VCC)
/plc_disp/CA1: M17.2, U6.1 (CA), U6.6 (CA)
/plc_disp/CA2: M18.2, U7.1 (CA), U7.6 (CA)
/plc_disp/CA3: M19.2, U8.1 (CA), U8.6 (CA)
/plc_disp/CA4: M20.2, U9.1 (CA), U9.6 (CA)
/plc_disp/P_SEL_1: M17.1, R33.1
/plc_disp/P_SEL_2: M18.1, R34.1
/plc_disp/P_SEL_3: M19.1, R35.1
/plc_disp/P_SEL_4: M20.1, R36.1
/tim_disp/A: R21.2, T1.14, T2.14
/tim_disp/A2: R29.2, T3.14, T4.14
/tim_disp/B: R20.2, T1.16, T2.16
/tim_disp/B2: R28.2, T3.16, T4.16
/tim_disp/C: R19.2, T1.13, T2.13
/tim_disp/C1: M1.2, T1.2
/tim_disp/C2: M2.2, T1.1
/tim_disp/C3: M3.2, T1.8
/tim_disp/C4: M4.2, T1.6
/tim_disp/C5: M5.2, T2.2
/tim_disp/C6: M6.2, T2.1
/tim_disp/C7: M7.2, T2.8
/tim_disp/C8: M8.2, T2.6
/tim_disp/C9: M9.2, T3.2
/tim_disp/C10: M10.2, T3.1
/tim_disp/C11: M11.2, T3.8
/tim_disp/C12: M12.2, T3.6
/tim_disp/C13: M13.2, T4.2
/tim_disp/C14: M14.2, T4.1
/tim_disp/C15: M15.2, T4.8
/tim_disp/C16: M16.2, T4.6
/tim_disp/C_2: R27.2, T3.13, T4.13
/tim_disp/D: R18.2, T1.3, T2.3
/tim_disp/D2: R26.2, T3.3, T4.3
/tim_disp/DP1: R22.2, T1.7, T2.7
/tim_disp/DP2: R30.2, T3.7, T4.7
/tim_disp/E: R17.2, T1.5, T2.5
/tim_disp/E2: R25.2, T3.5, T4.5
/tim_disp/F: R24.2, T1.11, T2.11
/tim_disp/F2: R32.2, T3.11, T4.11
/tim_disp/G: R23.2, T1.15, T2.15
/tim_disp/G2: R31.2, T3.15, T4.15
/tim_disp/R1: R1.2, U4.15 (~Y0)
/tim_disp/R2: R2.2, U4.14 (~Y1)
/tim_disp/R3: R3.2, U4.13 (~Y2)
/tim_disp/R4: R4.2, U4.12 (~Y3)
/tim_disp/R5: R5.2, U4.11 (~Y4)
/tim_disp/R6: R6.2, U4.10 (~Y5)
/tim_disp/R7: R7.2, U4.9 (~Y6)
/tim_disp/R8: R8.2, U4.7 (~Y7)
/tim_disp/R25: R9.2, U5.15 (~Y0)
/tim_disp/R26: R10.2, U5.14 (~Y1)
/tim_disp/R27: R11.2, U5.13 (~Y2)
/tim_disp/R28: R12.2, U5.12 (~Y3)
/tim_disp/R29: R13.2, U5.11 (~Y4)
/tim_disp/R30: R14.2, U5.10 (~Y5)
/tim_disp/R31: R15.2, U5.9 (~Y6)
/tim_disp/R32: R16.2, U5.7 (~Y7)
GND: GND1.1, GND2.1, GND3.1, GND4.1, GND5.1, GND6.1, GND7.1, GND8.1, J1.24, M17.3, M18.3, M19.3, M20.3, R41.2, R42.2, R43.2, R44.2, U2.11 (GND), U3.11 (GND), U4.4 (~E0), U4.5 (~E1), U4.8 (GND), U5.4 (~E0), U5.5 (~E1), U5.8 (GND)
unnamed: M1.1, R1.1
unnamed: M2.1, R2.1
unnamed: M3.1, R3.1
unnamed: M4.1, R4.1
unnamed: M5.1, R5.1
unnamed: M6.1, R6.1
unnamed: M7.1, R7.1
unnamed: M8.1, R8.1
unnamed: M9.1, R9.1
unnamed: M10.1, R10.1
unnamed: M11.1, R11.1
unnamed: M12.1, R12.1
unnamed: M13.1, R13.1
unnamed: M14.1, R14.1
unnamed: M15.1, R15.1
unnamed: M16.1, R16.1
unnamed: R24.1, U2.19 (*Y1)
unnamed: R23.1, U2.18 (*Y2)
unnamed: R22.1, U2.17 (*Y3)
unnamed: R21.1, U2.16 (*Y4)
unnamed: R20.1, U2.15 (*Y5)
unnamed: R19.1, U2.14 (*Y6)
unnamed: R18.1, U2.13 (*Y7)
unnamed: R17.1, U2.12 (*Y8)
unnamed: R32.1, U3.19 (*Y1)
unnamed: R31.1, U3.18 (*Y2)
unnamed: R30.1, U3.17 (*Y3)
unnamed: R29.1, U3.16 (*Y4)
unnamed: R28.1, U3.15 (*Y5)
unnamed: R27.1, U3.14 (*Y6)
unnamed: R26.1, U3.13 (*Y7)
unnamed: R25.1, U3.12 (*Y8)
PA0: U1.1, U6.10 (A), U7.10 (A), U8.10 (A), U9.10 (A)
PA1: U1.2, U6.9 (B), U7.9 (B), U8.9 (B), U9.9 (B)
PA2: U1.3, U6.8 (C), U7.8 (C), U8.8 (C), U9.8 (C)
PA3: U1.4, U6.5 (D), U7.5 (D), U8.5 (D), U9.5 (D)
PA4: U1.5, U6.4 (E), U7.4 (E), U8.4 (E), U9.4 (E)
PA5: U1.6, U6.2 (F), U7.2 (F), U8.2 (F), U9.2 (F)
PA6: U1.7, U6.3 (G), U7.3 (G), U8.3 (G), U9.3 (G)
PA7: R33.2, U1.8
PA8: R34.2, U1.9
PA9: R35.2, U1.10
PA10: R36.2, U1.11
PA11: PA11.1, PT1.2 (-), R41.1, U1.12
PA12: PA12.1, PT2.2 (-), R42.1, U1.13
PA13: PA13.1, PT3.2 (-), R43.1, U1.14
PA14: PA14.1, PT4.2 (-), R44.1, U1.15
PB0: J1.1, U2.7 (D6)
PB1: J1.2, U2.5 (D4)
PB2: J1.3, U2.8 (D7)
PB3: J1.4, U2.2 (D1)
PB4: J1.5, U2.3 (D2)
PB5: J1.6, U2.9 (D8)
PB6: J1.7, U2.6 (D5)
PB7: J1.8, U2.4 (D3)
PB8: J1.9, U4.1 (A0)
PB9: J1.10, U4.2 (A1)
PB10: J1.11, U4.3 (A2)
PC0: J1.12, U3.7 (D6)
PC1: J1.13, U3.5 (D4)
PC2: J1.14, U3.8 (D7)
PC3: J1.15, U3.2 (D1)
PC4: J1.16, U3.3 (D2)
PC5: J1.17, U3.9 (D8)
PC6: J1.18, U3.6 (D5)
PC7: J1.19, U3.4 (D3)
PC8: J1.20, U5.1 (A0)
PC9: J1.21, U5.2 (A1)
PC10: J1.22, U5.3 (A2)

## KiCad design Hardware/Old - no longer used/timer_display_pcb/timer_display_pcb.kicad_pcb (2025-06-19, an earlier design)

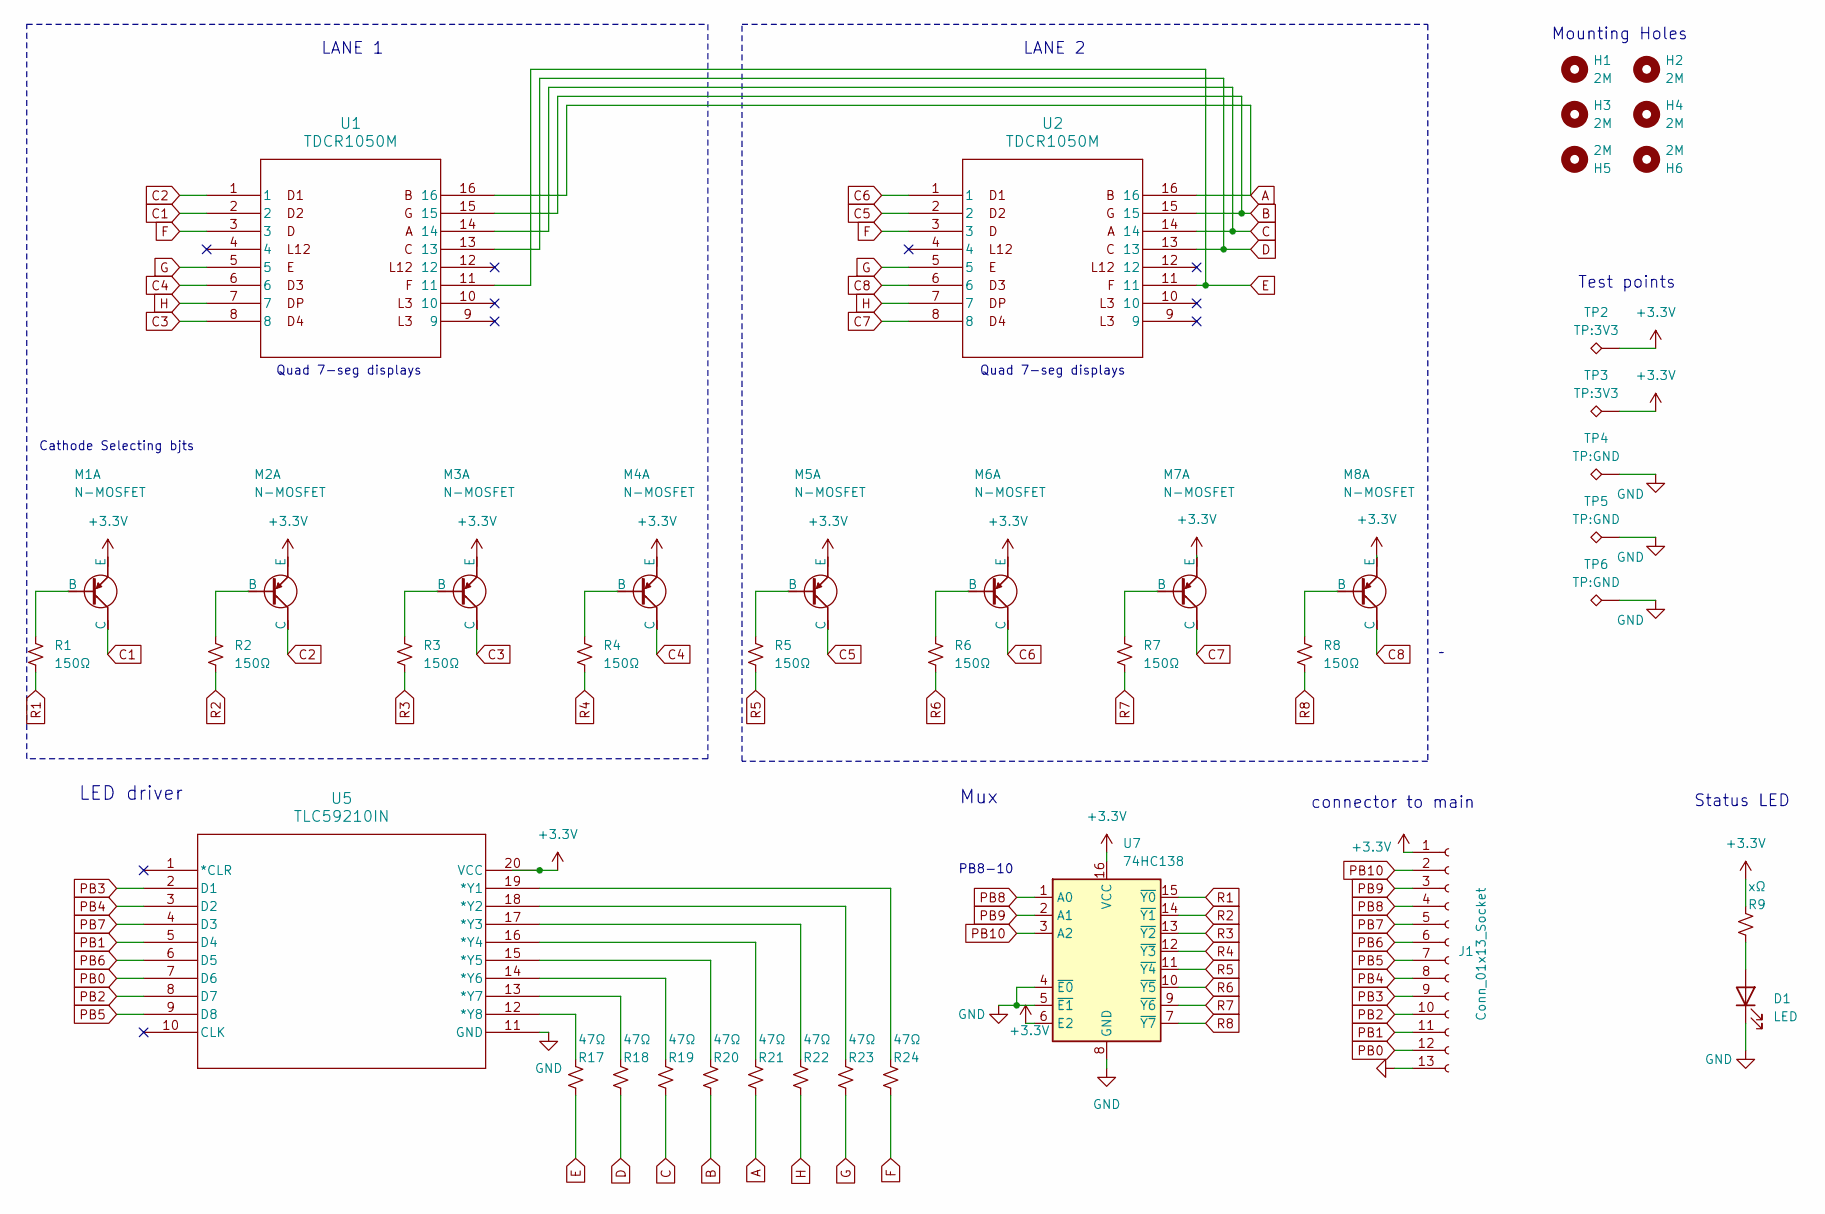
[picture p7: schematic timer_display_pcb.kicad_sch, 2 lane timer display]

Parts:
D1: LED; LED_0805_2012Metric
H1, H2, H3, H4, H5, H6: 2M; MountingHole_4.3mm_M4
J1: Conn_01x13_Socket; JST_EH_S13B-EH_1x13_P2.50mm_Horizontal
M1, M2, M3, M4, M5, M6, M7, M8: N-MOSFET; TO-236AB_SOT23_NEX
R1, R2, R3, R4, R5, R6, R7, R8: 150Ω; R_0805_2012Metric_Pad1.20x1.40mm_HandSolder
R9: xΩ; R_0805_2012Metric_Pad1.20x1.40mm_HandSolder
R17, R18, R19, R20, R21, R22, R23, R24: 47Ω; R_0805_2012Metric_Pad1.20x1.40mm_HandSolder
TP2, TP3: TP:3V3; TestPoint_Pad_2.0x2.0mm
TP4, TP5, TP6: TP:GND; TestPoint_Pad_2.0x2.0mm
U1, U2: TDCR1050M; TDCG1060M_VIS
U5: TLC59210IN; SOP65P640X120-20N
U7: 74HC138; SOIC127P600X175-16N

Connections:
+3.3V: J1.1, M1.1 (E), M2.1 (E), M3.1 (E), M4.1 (E), M5.1 (E), M6.1 (E), M7.1 (E), M8.1 (E), R9.1, TP2.1, TP3.1, U5.20 (VCC), U7.6 (E2), U7.16 (VCC)
A: R21.2, U1.16, U2.16
B: R20.2, U1.15, U2.15
C: R19.2, U1.14, U2.14
C1: M1.3 (C), U1.2
C2: M2.3 (C), U1.1
C3: M3.3 (C), U1.8
C4: M4.3 (C), U1.6
C5: M5.3 (C), U2.2
C6: M6.3 (C), U2.1
C7: M7.3 (C), U2.8
C8: M8.3 (C), U2.6
D: R18.2, U1.13, U2.13
E: R17.2, U1.11, U2.11
F: R24.2, U1.3, U2.3
G: R23.2, U1.5, U2.5
GND: D1.1 (K), J1.13, TP4.1, TP5.1, TP6.1, U5.11 (GND), U7.4 (~E0), U7.5 (~E1), U7.8 (GND)
H: R22.2, U1.7, U2.7
unnamed: D1.2 (A), R9.2
unnamed: M1.2 (B), R1.1
unnamed: M2.2 (B), R2.1
unnamed: M3.2 (B), R3.1
unnamed: M4.2 (B), R4.1
unnamed: M5.2 (B), R5.1
unnamed: M6.2 (B), R6.1
unnamed: M7.2 (B), R7.1
unnamed: M8.2 (B), R8.1
unnamed: R24.1, U5.19 (*Y1)
unnamed: R23.1, U5.18 (*Y2)
unnamed: R22.1, U5.17 (*Y3)
unnamed: R21.1, U5.16 (*Y4)
unnamed: R20.1, U5.15 (*Y5)
unnamed: R19.1, U5.14 (*Y6)
unnamed: R18.1, U5.13 (*Y7)
unnamed: R17.1, U5.12 (*Y8)
PB0: J1.12, U5.7 (D6)
PB1: J1.11, U5.5 (D4)
PB2: J1.10, U5.8 (D7)
PB3: J1.9, U5.2 (D1)
PB4: J1.8, U5.3 (D2)
PB5: J1.7, U5.9 (D8)
PB6: J1.6, U5.6 (D5)
PB7: J1.5, U5.4 (D3)
PB8: J1.4, U7.1 (A0)
PB9: J1.3, U7.2 (A1)
PB10: J1.2, U7.3 (A2)
R1: R1.2, U7.15 (~Y0)
R2: R2.2, U7.14 (~Y1)
R3: R3.2, U7.13 (~Y2)
R4: R4.2, U7.12 (~Y3)
R5: R5.2, U7.11 (~Y4)
R6: R6.2, U7.10 (~Y5)
R7: R7.2, U7.9 (~Y6)
R8: R8.2, U7.7 (~Y7)

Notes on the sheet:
LANE 1
LANE 2
connector to main
Cathode Selecting bjts
PB8-10
Quad 7-seg displays
Status LED
Test points
LED driver
Mounting Holes
Mux

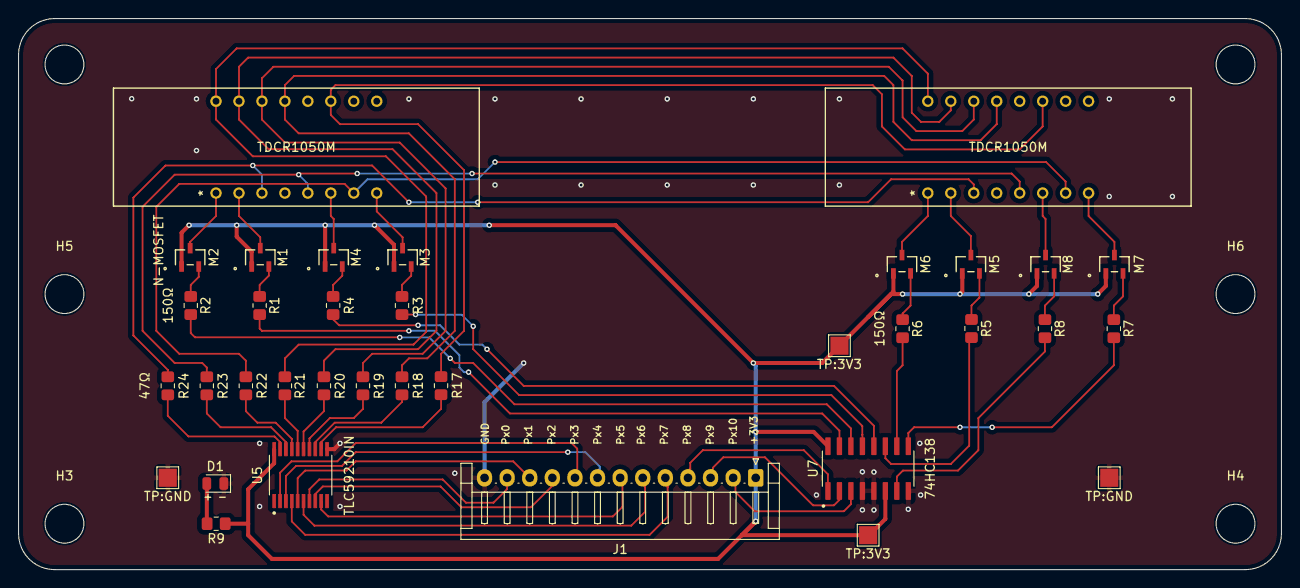
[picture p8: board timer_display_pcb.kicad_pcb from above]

Board: 2 copper layers, 139.7 x 61.0 mm, 42 parts (1 on the bottom side), 54 nets.

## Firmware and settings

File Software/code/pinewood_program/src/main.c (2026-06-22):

#include "stm32f0xx.h"
#include <stdint.h>
#include <stdio.h>

#include "display.h"
#include "race.h"
#include "pins.h"
#include "uart.h"

void internal_clock(void);

static void enable_gpio_clocks(void)
{
    RCC->AHBENR |= RCC_AHBENR_GPIOAEN | RCC_AHBENR_GPIOBEN | RCC_AHBENR_GPIOCEN;
    /* GPIOD enabled in uart5_init() for PD2 RX. */
}

/*
 * Configure PA0-PA10 (or PB/PC) as outputs:
 * MODER nibble pattern 0101 0101 0101 0101 0100 = output on pins 0-10.
 */
static void configure_display_port(GPIO_TypeDef *port)
{
    port->MODER &= ~0x03FF03FFU;
    port->MODER |= 0x01540154U;
}

static void configure_inputs(void)
{
    /* PB11-PB14 finish sensors — input with pull-up. */
    FINISH_PORT->MODER &= ~0x3C000000U;
    FINISH_PORT->PUPDR &= ~0x3C000000U;
    FINISH_PORT->PUPDR |= 0x28000000U;

    /* PC11 start switch — input with pull-up. */
    START_PORT->MODER &= ~(3U << (11U * 2U));
    START_PORT->PUPDR &= ~(3U << (11U * 2U));
    START_PORT->PUPDR |= (1U << (11U * 2U));

    /* PA15 reset button — input with pull-up (PC12 is UART5_TX). */
    RESET_PORT->MODER &= ~(3U << (15U * 2U));
    RESET_PORT->PUPDR &= ~(3U << (15U * 2U));
    RESET_PORT->PUPDR |= (1U << (15U * 2U));
}

static void configure_status_leds(void)
{
    /* PC13, PC14, PC15 — outputs, start off. */
    GPIOC->MODER &= ~0xFC000000U;
    GPIOC->MODER |= 0x54000000U;
    GPIOC->ODR &= ~(LED_READY_PIN | LED_RUNNING_PIN | LED_FINISHED_PIN);
}

/* TIM14 — 48 MHz / 48 / 1000 = 1 kHz lane time ticks. */
static void setup_tim14(void)
{
    RCC->APB1ENR |= RCC_APB1ENR_TIM14EN;

    TIM14->PSC = 48U - 1U;
    TIM14->ARR = 1000U - 1U;
    TIM14->DIER |= TIM_DIER_UIE;
    NVIC->ISER[0] = (1U << TIM14_IRQn);
    TIM14->CR1 |= TIM_CR1_CEN;
}

/* TIM6 — 48 MHz / 48 / 500 = 2 kHz sensor poll + display mux. */
static void setup_tim6(void)
{
    RCC->APB1ENR |= RCC_APB1ENR_TIM6EN;

    TIM6->PSC = 48U - 1U;
    TIM6->ARR = 500U - 1U;
    TIM6->DIER |= TIM_DIER_UIE;
    NVIC->ISER[0] = (1U << TIM6_DAC_IRQn);
    TIM6->CR1 |= TIM_CR1_CEN;
}

static void update_status_leds(void)
{
    switch (race_state()) {
    case RACE_IDLE:
        display_set_status_leds(1, 0, 0);
        break;
    case RACE_RUNNING:
        display_set_status_leds(0, 1, 0);
        break;
    case RACE_FINISHED:
        display_set_status_leds(0, 0, 1);
        break;
    }
}

void TIM14_IRQHandler(void)
{
    TIM14->SR &= ~TIM_SR_UIF;
    race_tick_times();
}

void TIM6_DAC_IRQHandler(void)
{
    TIM6->SR &= ~TIM_SR_UIF;
    race_poll_inputs();
    display_refresh_step();
    update_status_leds();
}

int main(void)
{
    internal_clock();
    enable_gpio_clocks();

    configure_display_port(PLACEMENT_PORT);
    configure_display_port(TIMER_L12_PORT);
    configure_display_port(TIMER_L34_PORT);
    configure_inputs();
    configure_status_leds();

    race_init();
    display_init();
    uart5_init();

    setup_tim14();
    setup_tim6();

    puts("PINEWOOD READY\r\n");

    while (1) {
        __WFI();
    }
}

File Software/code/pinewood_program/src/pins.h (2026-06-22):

#ifndef PINEWOOD_PINS_H
#define PINEWOOD_PINS_H

#include "stm32f0xx.h"
#include <stdint.h>

/*
 * ============================================================================
 *  Pinewood Derby Timer — GPIO map (STM32F091RCT6)
 * ============================================================================
 *
 *  All pin names refer to the MCU package pin function.
 *  Hex masks are bit positions in the port ODR/IDR/BSRR (bit N = PN).
 *
 *  Display data uses TLC59211 parallel inputs D1-D8 (port bits 0-7) plus
 *  74HC138 mux address A0-A2 (port bits 8-10).  Eleven pins per bank.
 *
 *  See INDEX.md and README2.md for full software documentation.
 * ============================================================================
 */

#define NUM_LANES 4

/* -------------------------------------------------------------------------- */
/*  Placement display — GPIOA PA0 .. PA10 (11 pins)                           */
/* -------------------------------------------------------------------------- */
#define PLACEMENT_PORT GPIOA

/* Bits PA0-PA10 enabled: 0x07FF */
#define DISPLAY_PIN_MASK 0x07FFU /* PA0=bit0 .. PA10=bit10 */

/* PA0  — TLC59211 D1 / segment bus bit 0 */
/* PA1  — TLC59211 D2 / segment bus bit 1 */
/* PA2  — TLC59211 D3 / segment bus bit 2 */
/* PA3  — TLC59211 D4 / segment bus bit 3 */
/* PA4  — TLC59211 D5 / segment bus bit 4 */
/* PA5  — TLC59211 D6 / segment bus bit 5 */
/* PA6  — TLC59211 D7 / segment bus bit 6 */
/* PA7  — TLC59211 D8 / segment bus bit 7 */
/* PA8  — 74HC138 A0 (mux bit 0) */
/* PA9  — 74HC138 A1 (mux bit 1) */
/* PA10 — 74HC138 A2 (mux bit 2) */

/* -------------------------------------------------------------------------- */
/*  Timer display lanes 1 & 2 — GPIOB PB0 .. PB10                             */
/* -------------------------------------------------------------------------- */
#define TIMER_L12_PORT GPIOB

/* PB0  — TLC59211 D1 / segment bus bit 0 */
/* PB1  — TLC59211 D2 */
/* PB2  — TLC59211 D3 */
/* PB3  — TLC59211 D4 */
/* PB4  — TLC59211 D5 */
/* PB5  — TLC59211 D6 */
/* PB6  — TLC59211 D7 */
/* PB7  — TLC59211 D8 */
/* PB8  — 74HC138 A0 (mux bit 0) */
/* PB9  — 74HC138 A1 (mux bit 1) */
/* PB10 — 74HC138 A2 (mux bit 2) */

/* -------------------------------------------------------------------------- */
/*  Timer display lanes 3 & 4 — GPIOC PC0 .. PC10                             */
/* -------------------------------------------------------------------------- */
#define TIMER_L34_PORT GPIOC

/* PC0  — TLC59211 D1 / segment bus bit 0 */
/* PC1  — TLC59211 D2 */
/* PC2  — TLC59211 D3 */
/* PC3  — TLC59211 D4 */
/* PC4  — TLC59211 D5 */
/* PC5  — TLC59211 D6 */
/* PC6  — TLC59211 D7 */
/* PC7  — TLC59211 D8 */
/* PC8  — 74HC138 A0 (mux bit 0) */
/* PC9  — 74HC138 A1 (mux bit 1) */
/* PC10 — 74HC138 A2 (mux bit 2) */

/* -------------------------------------------------------------------------- */
/*  Race control inputs                                                         */
/* -------------------------------------------------------------------------- */

/* PC11 — start lever / release switch, mask 0x0800 (bit 11) */
#define START_PORT     GPIOC
#define START_PIN_MASK (1U << 11) /* PC11, 0x0800 */

/*
 * PA15 — reset button (placeholder until mainboard routing is final).
 * Mask 0x8000 (bit 15).  PC12 is reserved for UART5_TX.
 */
#define RESET_PORT     GPIOA
#define RESET_PIN_MASK (1U << 15) /* PA15, 0x8000 */

/* Finish-line IR receivers — GPIOB PB11 .. PB14, one per lane */
#define FINISH_PORT GPIOB

#define FINISH_LANE_MASK(lane) (1U << (11 + (lane)))
/* Lane 1: PB11  0x0800  (bit 11) */
/* Lane 2: PB12  0x1000  (bit 12) */
/* Lane 3: PB13  0x2000  (bit 13) */
/* Lane 4: PB14  0x4000  (bit 14) */

/* -------------------------------------------------------------------------- */
/*  UART5 — FT232RL USB-TTL (not used as GPIO)                                 */
/* -------------------------------------------------------------------------- */
/* PC12 — USART5_TX, AF2, mask 0x1000 (bit 12) — see uart.c */
/* PD2  — USART5_RX, AF2, mask 0x0004 (bit 2)  — see uart.c */

/* -------------------------------------------------------------------------- */
/*  Status LEDs on mainboard — GPIOC PC13 .. PC15, active high                */
/* -------------------------------------------------------------------------- */
#define LED_READY_PORT    GPIOC
#define LED_RUNNING_PORT  GPIOC
#define LED_FINISHED_PORT GPIOC

#define LED_READY_PIN    (1U << 13) /* PC13, 0x2000 */
#define LED_RUNNING_PIN  (1U << 14) /* PC14, 0x4000 */
#define LED_FINISHED_PIN (1U << 15) /* PC15, 0x8000 */

/* -------------------------------------------------------------------------- */
/*  Sensor polarity (change if hardware inverts)                              */
/* -------------------------------------------------------------------------- */
/* 1 = pressed / beam-broken reads logic high.  0 = active low. */
#define BUTTON_ACTIVE_HIGH        1
#define FINISH_SENSOR_ACTIVE_HIGH 1
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

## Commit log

2025-05-01 began schematic
    [infared_sensors.kicad_sch, pinewood_timer.kicad_pcb, pinewood_timer.kicad_sch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]
2025-05-01 did some more work on the time displays
    pb and pa maybe or pc. pa might need to be adc if i cant just transistor/relay it or something
    [seven_seg_display_timer.kicad_sch]
2025-05-01 worked on schematic more
    [infared_sensors.kicad_sch, pinewood_timer.kicad_sch, power_management.kicad_sch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]
2025-05-01 updated bom
    [pinewoodBOM.xlsx, pinewood_bom.csv]
2025-05-01 edited schematic
    added descriptions to sheets
    chose sensor pins
    added missing items to bom
    [pinewood_timer.kicad_sch, seven_seg_display_timer.kicad_sch]
2025-05-05 added pins
    [infared_sensors.kicad_sch, pinewood_timer.kicad_sch, seven_seg_display_timer.kicad_sch]
2025-06-07 worked on the ir sensors and placement display
    [breakout_board.kicad_pcb, breakout_board.kicad_sch, pinewood_timer.kicad_sch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]
2025-06-07 edited placement timer schematic since i can never make up my mind
    [infared_sensors.kicad_sch, pinewood_timer.kicad_sch, seven_seg_display_placement.kicad_sch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]
2025-06-16 keep forgetting ot push - a lot of updates
    fixed stm pinout. needs a lot more support than i was providing
    [infared_sensors.kicad_sch, pinewood_timer.kicad_sch, seven_seg_display_placement.kicad_sch]
2025-06-19 finished 2 lane display pcb
    [seven_seg_display_placement.kicad_sch, seven_seg_display_timer.kicad_sch, timer_display_pcb.kicad_pcb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]
2025-07-08 Create schematics.md
    added 2 lane tmr dsp
2025-07-12 edited schematic.
    realized that mux and led driver only saved me 1 pin and added a lot of extra nonsense
    [display_15_in.kicad_pcb, display_15_in.kicad_sch, mainboard.kicad_pcb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]
2025-07-13 added full end of track display board
    [display_15_in.kicad_sch, plc_disp.kicad_sch, sensor.kicad_sch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]
2025-07-14 edited layout
    [display_15_in.kicad_pcb, display_15_in.kicad_sch, plc_disp.kicad_sch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]
2025-07-14 removed files
    [breakout_board.kicad_pcb, breakout_board.kicad_sch]
2025-07-15 more work on pcb
    finished house season 2 and made decent progress (i think) on the pcb. if it is bad ill see tomorrow lol
    [display_15_in.kicad_pcb, mainboard.kicad_sch]
2025-07-19 routed more traces
    [display_15_in.kicad_pcb, display_15_in.kicad_sch, sensor.kicad_sch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]
2025-07-20 added more traces lowkey sufferig
    [display_15_in.kicad_pcb]
2025-07-22 avoiding doing the via calculations or at least researching how to do them so i just added silkscreen stuff
    [display_15_in.kicad_pcb]
2025-07-26 power traces, gnd plane vias, and test points
    [display_15_in.kicad_sch, plc_disp.kicad_sch, sensor.kicad_sch]
2025-07-27 began work on mainboard
    mostly schematic but i did assign footprints (if you even consider that to be working on the pcb)
    power in from usb and ONLY power from usb - no dp just vbus and gnd. still dnt know what cc or shield is but i can figure that out later
    jtag and usb-ttl for programming. will not be powered by usb while programmed.
    [display_15_in.kicad_pcb, display_15_in.kicad_sch, mainboard.kicad_sch]
2025-07-27 updated mainboard schematic
    organization and power
    [mainboard.kicad_sch]
2025-07-27 forgor race reset button
    theres a reset on the board and a reset on the side for them to hit to clear it for the next race
    [mainboard.kicad_sch]
2025-08-03 updated schematic
    added:
    -footprints
    -status leds
    -libraries
    -connectors
    separated into sheets since too many components on pange
    [leds.kicad_sch, mainboard.kicad_pcb, mainboard.kicad_sch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]
2025-08-03 pushing for the evening
    didnt add much, just moved things around and fixed footprints
    [mainboard.kicad_pcb, mainboard.kicad_sch, programming.kicad_sch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]
2025-08-04 Lowkey forgot the start switch so i added that
    [mainboard.kicad_pcb, programming.kicad_sch, stm.kicad_sch]
2025-08-05 layout
    worked on the layput but im actively falling asleep while working on it so im going to call it a day
    [mainboard.kicad_pcb, programming.kicad_sch, stm.kicad_sch]
2025-08-05 add layer
    [mainboard.kicad_pcb, mainboard.kicad_sch, programming.kicad_sch]
2025-08-06 routed traces
    [mainboard.kicad_pcb, programming.kicad_sch, stm.kicad_sch]
2025-08-06 display and design rules
    [display_15_in.kicad_pcb]
2025-08-06 gitignore fixed finally
    [display_15_in.kicad_sch]
2025-08-06 cleanup again
    a lot of old unused files in the way
    [infared_sensors.kicad_sch, pinewood_timer.kicad_pcb, pinewood_timer.kicad_sch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]
2025-08-07 lowkey accidentally deleted everything but i brought a previous commit back since i am a true girlboss
    like i deleted inner layers since i thought iw as looking at a diff board
    [display_15_in.kicad_pcb, display_15_in.step, mainboard.kicad_pcb]
2025-08-07 final push for the night
    [display_15_in.kicad_pcb, mainboard.kicad_pcb]
2025-08-07 fixed schematic pcb agreement errors
    [mainboard.kicad_pcb, mainboard.kicad_sch, stm.kicad_sch]
2025-08-08 generated gbr files
    [display_15_in-B_Cu.gbr, display_15_in-B_Mask.gbr, display_15_in-B_Paste.gbr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]
2025-08-13 gbr files
    ordered pcbs
    [display_15_in.kicad_pcb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]
2025-08-13 enable ports
    setup pin config
    [mainboard.kicad_pcb]
2025-09-18 testing new git form + fixed funny ground wire
    [display_15_in.kicad_sch, plc_disp.kicad_sch, sensor.kicad_sch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]
2025-09-18 fixed what i messed up just now
    [display_15_in.kicad_sch]
2026-06-22 i let the robot loose
    once i get my programming cables ill test it. i have never tried this before so well see how well it does
    i need to remake the board as well. usbc for easy compatibility would be nice
    [mainboard-B_Cu.gbr, mainboard-B_Mask.gbr, mainboard-B_Paste.gbr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]
2026-09-30 created mainboard v2
    mainboard v2 will replace v1. i will also update the footprint for the led display
    [mainboard.kicad_sch, mainboardv2.kicad_sch, programming.kicad_sch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]
